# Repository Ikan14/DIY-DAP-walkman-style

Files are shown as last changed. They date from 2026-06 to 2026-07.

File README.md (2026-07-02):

# DIY-DAP-walkman-style
Hear your favourite music without any interruption by the palm of your hands,
with an old school vibes going on with DIY DAP Walkman style.

## Description 
  With ESP32 as the brain (Main processor) you could make a cheap DAP (Digital Audio Player) filled with your favouri♪te 
Music playlist, with ESP32 as the microcontroller, SD card module to filled with your Mp3 music files and some Audio jack 3.5 mm to hear it throught your earphone
with some niche button like the walkman has. And you could add display to make some UI ! >:D.

## Project Preview
Assembly 1 (4)
Assembly 1

## 3D model
Bwlow here is the full CAD assembly of the project, the .STEP files on the /CAD Files Folder
Assembly 1 (2)
Assembly 1 (4)

## Source Design
https://cad.onshape.com/documents/cdf923aa097df220a4b09fb1/w/958292e6abd58ac5f25ffee2/e/462f93d2c8d04da2a323aa71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

## Wiring Diagram
Shows how the ESP32 connect or wired with the DAC and other components


## Features :D
- Play Mp3 files by the SD card
- The button have contorol to Play/pause, Next, Previous
- 3.5 mm headphone or earphone outpur
- "Walkman Style" with 3D Printed case

## Component I use (almost everthing in module)
- ESP32-C3-DevKit module (mainboard)
- PCM5102 DAC Module with audiojack 3.5 mm
 (if the DAC module doesn't have any audio jack you need) audiojack 3.5 mm
- Micro SDcard Module
- OLED I2C 0.91'' inch
- MT608 Modul Step Up Boost DC to DC 2A USB Type-C
- TP4056 module TYPE-C
- 3.7 V 18650 li ion battery
- One battery holder
- 3 Push button

## BOM (Bill of Materials)
BOM Files on the /BOM (Bill Of Materials) folder ;)
Components List

| Name | Purpose | Qty | Total Cost (USD) | Source / Link | Distributor |
| :--- | :--- | :---: | :---: | :---: | :---: |
| **Tactile Switch** | As the control of the DAP | 3 | $0.17 | [Link](https://tk.tokopedia.com/ZSCdCuva5/) | Tokopedia |
| **One battery holder** | To hold the battery | 1 | $0.27 | [Link](https://tk.tokopedia.com/ZSCdCpkyx/) | Tokopedia |
| **3.7 V 18650 li-ion battery** | As the power supply | 1 | $0.49 | [Link](https://tk.tokopedia.com/ZSCdCrD4L/) | Tokopedia |
| **TP4056 module TYPE-C** | To charge up the battery | 1 | $0.34 | [Link](https://tk.tokopedia.com/ZSCdQsH1c/) | Tokopedia |
| **MT608 Modul Step Up Boost DC to DC 2A USB TYPE C** | For stepping up the current | 1 | $0.63 | [Link](https://tk.tokopedia.com/ZSCdQSWaG/) | Tokopedia |
| **OLED I2C 0.91'' inch Module** | As the screen | 1 | $1.76 | [Link](https://tk.tokopedia.com/ZSCdxTECL/) | Tokopedia |
| **Micro SD card module reader** | To store our music file | 1 | $0.56 | [Link](https://tk.tokopedia.com/ZSCdQ1gt9/) | Tokopedia |
| **PCM5102 DAC Module with audiojack 3.5 mm** | For changing Digital signal into Analog | 1 | $2.80 | [Link](https://tk.tokopedia.com/ZSCdxNCav/) | Tokopedia |
| **ESP32 C3 DevKit** | As the mainboard | 1 | $4.54 | [Link](https://tk.tokopedia.com/ZSCdxLQtW/) | Tokopedia |

---
*Note: Costs are estimation values in USD based on local distributor pricing.*

## Firmware
FIrmware is on the /Firmware folder and it is written using C++ in Arduino IDE framework

## Files Included
- CAD files (.STEP & source)
- Wiring Diagram
- BOM
- firmware

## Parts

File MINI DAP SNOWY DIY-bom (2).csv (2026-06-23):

Name | Purpose | Quantity | Total Cost (USD) | Link | Distributor
Tactile Switch | As the control of the DAP | 3 | 0.17 | https://tk.tokopedia.com/ZSCdCuva5/ | Tokopedia
One battery holder | To hold the battry | 1 | 0.27 | https://tk.tokopedia.com/ZSCdCpkyx/ | Tokopedia
3.7 V 18650 li ion battery | As the power supply | 1 | 0.49 | https://tk.tokopedia.com/ZSCdCrD4L/ | Tokopedia
TP4056 module TYPE-C | To charge up the battry | 1 | 0.34 | https://tk.tokopedia.com/ZSCdQsH1c/ | Tokopedia
MT608 Modul Step Up Boost DC to DC 2A USB TYPE C Type-C | For stepping Up the current | 1 | 0.63 | https://tk.tokopedia.com/ZSCdQSWaG/https://tk.tokopedia.com/ZSCdQSWaG/ | Tokopedia
OLED I2C 0.91'' inch Module | As the screen | 1 | 1.76 | https://tk.tokopedia.com/ZSCdxTECL/ | Tokopedia
Micro SDcard module reader | To store our music file | 1 | 0.56 | https://tk.tokopedia.com/ZSCdQ1gt9/ | Tokopedia
PCM5102 DAC Module with audiojack 3.5 mm | For changing Digital signal into Analog | 1 | 2.80 | https://tk.tokopedia.com/ZSCdxNCav/ | Tokopedia
ESP32 C3 DevKit | As the mainboard | 1 | 4.54 | https://tk.tokopedia.com/ZSCdxLQtW/ | Tokopedia

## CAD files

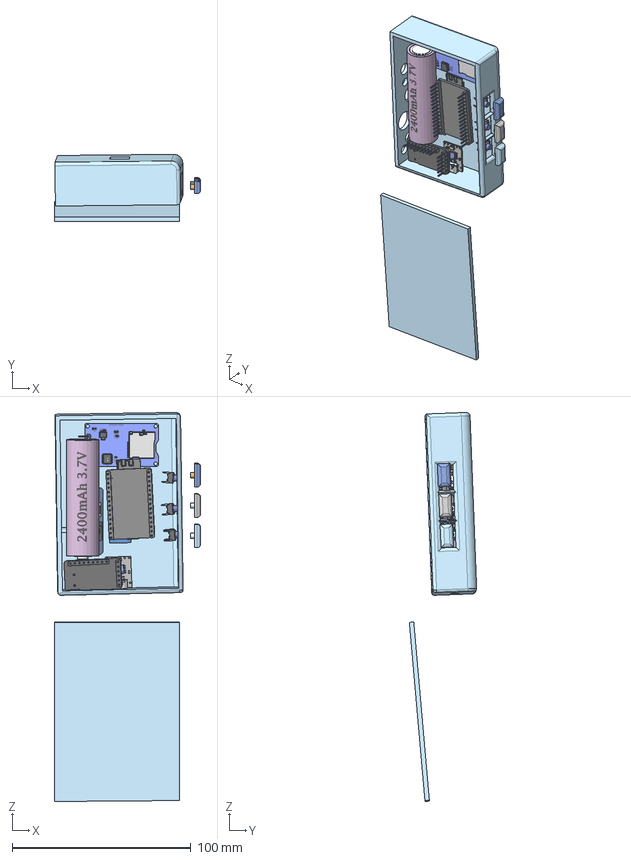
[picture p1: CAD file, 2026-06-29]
DAP_Walkman_v2_assembly.step
81.8 x 37.6 x 217.5 mm
TP4056 Mini x 29
Micro Momentary Tactile Tact Touch Push Button Switch, 6x6x6 mm v2 x 33
Surface 3
Valor predeterminado
2400mah li-ion cell v1 x 4
Surface 2
Surface 1
MT3608 v3 x 40
Pcb_e102
J2_PinHeader_1x09_P254mm_Vertical_94b9bb8abd76
J1_PinHeader_1x06_P254mm_Vertical_a7862d32d6b2
C13_C_0603_1608Metric_fe494fe29558 x 12
D1_LED_0603_1608Metric_b5c2f6ca02fa
R7_R_0603_1608Metric_fcd2d6c932f5 x 7
C2_C_0805_2012Metric_0ac201e7e1f9 x 2
U3_SOT_23_5_215b9efe0f9c x 2
U2_TSSOP_20_44x65mm_P065mm_d0068de2549f
J3_PJ-327A_7183a15533ae x 2
ESP32-C3-MINI-1_ESP32-C3-MINI-1 x 86
ESP32-C3-DEVKITM-1_ESP32-C3-DEVKITM-1 x 75
USB3080-30-00-A- x 12
CP2102N-A02-GQFN28_CP2102N-A02-GQFN28 x 31
1N5819HW-7-F_1N5819HW-7-F x 3
2SD0601A x 4
RESC-0603 x 39
Pin Header 4 x 1 TH 2.54mm Pitch x 8
OLED_0.91_128x32

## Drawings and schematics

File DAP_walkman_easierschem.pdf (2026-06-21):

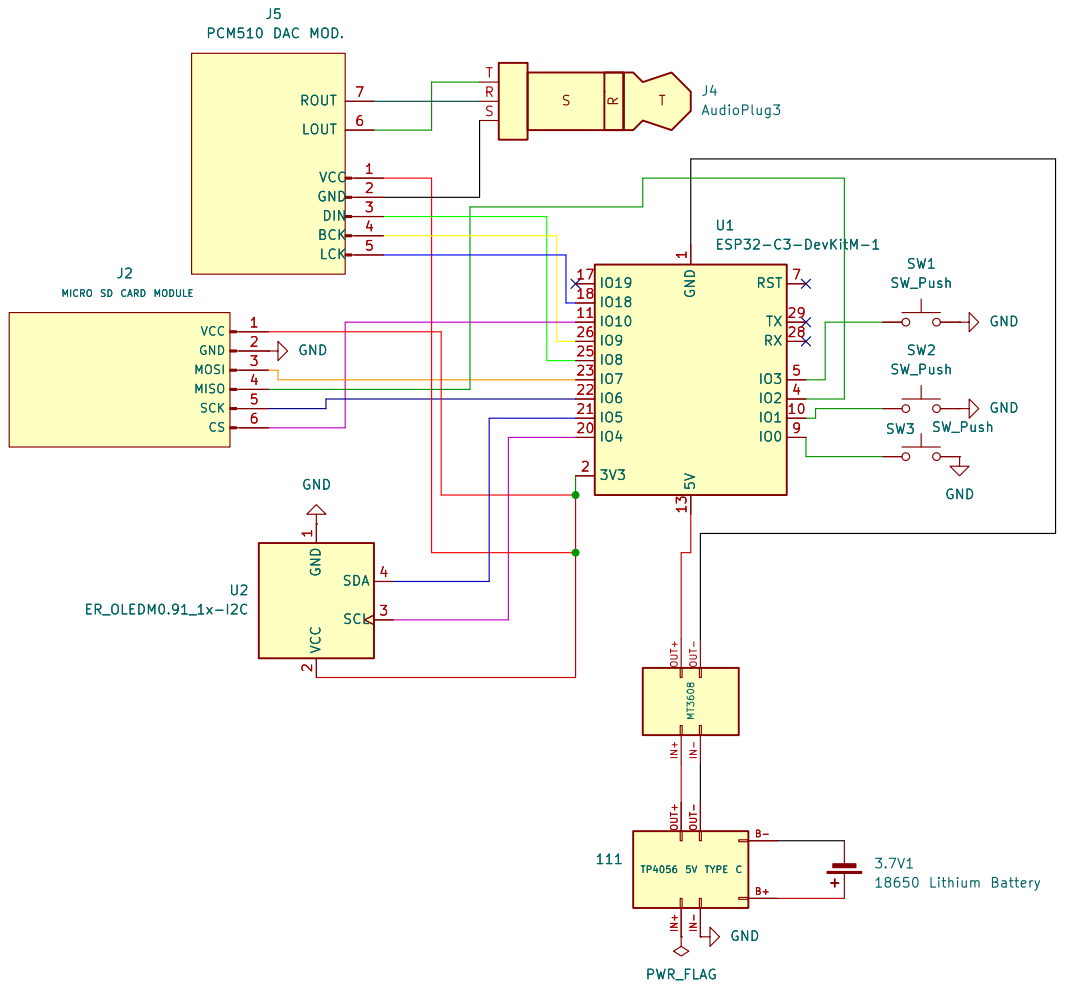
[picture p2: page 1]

Size: A4 | Rev:
KiCad E.D.A. 10.0.0 | Id: 1/1

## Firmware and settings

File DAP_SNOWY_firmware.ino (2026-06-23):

/*
 * MINI DAP SNOWY - Firmware v1.0
 * ESP32-C3 based Digital Audio Player
 * 
 * Pin Assignment:
 *   OLED  → SCL: IO4,  SDA: IO5
 *   SD    → MOSI: IO7, MISO: IO2, SCK: IO6, CS: IO10
 *   DAC   → DIN: IO8,  BCK: IO9,  LCK: IO18
 *   BTN   → SW1 (Play/Pause): IO3, SW2 (Next): IO1, SW3 (Prev): IO0
 * 
 * Libraries needed (install via Arduino Library Manager):
 *   - ESP8266Audio by Earle F. Philhower
 *   - U8g2 by oliver
 *   - SD (built-in ESP32)
 */

#include "Arduino.h"
#include "SD.h"
#include "SPI.h"
#include "Wire.h"
#include "U8g2lib.h"
#include "AudioFileSourceSD.h"
#include "AudioGeneratorMP3.h"
#include "AudioOutputI2S.h"

// ─── PIN DEFINITIONS ──────────────────────────────────────────
#define I2C_SCL     4
#define I2C_SDA     5

#define SD_MOSI     7
#define SD_MISO     2
#define SD_SCK      6
#define SD_CS       10

#define I2S_DIN     8
#define I2S_BCK     9
#define I2S_LCK     18

#define BTN_PLAY    3   // SW1 - Play / Pause
#define BTN_NEXT    1   // SW2 - Next track
#define BTN_PREV    0   // SW3 - Previous track

// ─── OBJECTS ──────────────────────────────────────────────────
U8G2_SSD1306_128X32_UNIVISION_F_HW_I2C oled(U8G2_R0, U8X8_PIN_NONE, I2C_SCL, I2C_SDA);

AudioGeneratorMP3 *mp3;
AudioFileSourceSD *file;
AudioOutputI2S    *out;

// ─── TRACK LIST ───────────────────────────────────────────────
#define MAX_TRACKS 50
char trackList[MAX_TRACKS][64];
int  trackCount   = 0;
int  currentTrack = 0;
bool isPlaying    = false;

// ─── BUTTON DEBOUNCE ──────────────────────────────────────────
unsigned long lastBtnPress[3] = {0, 0, 0};
#define DEBOUNCE_MS 200

// ─── HELPERS ──────────────────────────────────────────────────

// Scan SD root for .mp3 files
void scanTracks() {
  File root = SD.open("/");
  trackCount = 0;
  while (true) {
    File entry = root.openNextFile();
    if (!entry || trackCount >= MAX_TRACKS) break;
    String name = entry.name();
    if (!entry.isDirectory() && name.endsWith(".mp3")) {
      name = "/" + name;
      name.toCharArray(trackList[trackCount], 64);
      trackCount++;
    }
    entry.close();
  }
  root.close();
}

// Draw now-playing screen on OLED
void updateOLED() {
  oled.clearBuffer();
  oled.setFont(u8g2_font_6x10_tf);

  if (trackCount == 0) {
    oled.drawStr(0, 12, "No MP3 found!");
    oled.drawStr(0, 26, "Put files on SD");
  } else {
    // Track name (strip leading slash)
    String name = String(trackList[currentTrack]);
    if (name.startsWith("/")) name = name.substring(1);
    // Truncate if too long
    if (name.length() > 20) name = name.substring(0, 17) + "...";

    oled.drawStr(0, 10, isPlaying ? ">> NOW PLAYING" : "|| PAUSED");
    oled.drawStr(0, 22, name.c_str());

    // Track counter e.g. "2 / 5"
    String counter = String(currentTrack + 1) + " / " + String(trackCount);
    oled.drawStr(0, 32, counter.c_str());
  }
  oled.sendBuffer();
}

// Start playing currentTrack
void startTrack() {
  if (trackCount == 0) return;

  // Stop previous if running
  if (mp3 && mp3->isRunning()) {
    mp3->stop();
    delete mp3;
    delete file;
    mp3  = nullptr;
    file = nullptr;
  }

  file = new AudioFileSourceSD(trackList[currentTrack]);
  mp3  = new AudioGeneratorMP3();
  mp3->begin(file, out);
  isPlaying = true;
  updateOLED();
  Serial.printf("Playing: %s\n", trackList[currentTrack]);
}

void stopTrack() {
  if (mp3 && mp3->isRunning()) mp3->stop();
  isPlaying = false;
  updateOLED();
}

// ─── SETUP ────────────────────────────────────────────────────
void setup() {
  Serial.begin(115200);
  Serial.println("\n== MINI DAP SNOWY ==");

  // Buttons (INPUT_PULLUP → pressed = LOW)
  pinMode(BTN_PLAY, INPUT_PULLUP);
  pinMode(BTN_NEXT,  INPUT_PULLUP);
  pinMode(BTN_PREV,  INPUT_PULLUP);

  // OLED
  Wire.begin(I2C_SDA, I2C_SCL);
  oled.begin();
  oled.clearBuffer();
  oled.setFont(u8g2_font_6x10_tf);
  oled.drawStr(0, 16, "DAP SNOWY");
  oled.drawStr(0, 28, "Booting...");
  oled.sendBuffer();

  // SD Card
  SPI.begin(SD_SCK, SD_MISO, SD_MOSI, SD_CS);
  if (!SD.begin(SD_CS)) {
    Serial.println("SD Card FAILED!");
    oled.clearBuffer();
    oled.drawStr(0, 16, "SD Card Error!");
    oled.sendBuffer();
    while (true) delay(1000);
  }
  Serial.println("SD Card OK");

  // Scan tracks
  scanTracks();
  Serial.printf("Found %d tracks\n", trackCount);

  // I2S output → PCM5102
  out = new AudioOutputI2S();
  out->SetPinout(I2S_BCK, I2S_LCK, I2S_DIN);
  out->SetGain(0.8);  // 0.0 - 1.0 volume

  mp3  = nullptr;
  file = nullptr;

  updateOLED();

  // Auto-play first track
  if (trackCount > 0) startTrack();
}

// ─── LOOP ─────────────────────────────────────────────────────
void loop() {
  unsigned long now = millis();

  // ── Button: Play / Pause (SW1) ──
  if (digitalRead(BTN_PLAY) == LOW && now - lastBtnPress[0] > DEBOUNCE_MS) {
    lastBtnPress[0] = now;
    if (isPlaying) {
      stopTrack();
    } else {
      if (mp3 && !mp3->isRunning()) {
        mp3->begin(file, out);
        isPlaying = true;
        updateOLED();
      } else {
        startTrack();
      }
    }
  }

  // ── Button: Next (SW2) ──
  if (digitalRead(BTN_NEXT) == LOW && now - lastBtnPress[1] > DEBOUNCE_MS) {
    lastBtnPress[1] = now;
    currentTrack = (currentTrack + 1) % trackCount;
    startTrack();
  }

  // ── Button: Prev (SW3) ──
  if (digitalRead(BTN_PREV) == LOW && now - lastBtnPress[2] > DEBOUNCE_MS) {
    lastBtnPress[2] = now;
    currentTrack = (currentTrack - 1 + trackCount) % trackCount;
    startTrack();
  }

  // ── Feed audio decoder ──
  if (mp3 && mp3->isRunning()) {
    if (!mp3->loop()) {
      // Track finished → auto-next
      Serial.println("Track ended, playing next...");
      currentTrack = (currentTrack + 1) % trackCount;
      startTrack();
    }
  }
}

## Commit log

2026-04-07 Enhance README with project description and details
    Expanded project description to provide more details about the DIY DAP Walkman-style device, including its components and features.
2026-04-08 Create CAD Files
2026-04-08 Create Wiring Diagrams
2026-04-08 Create BOM (Bill Of Materials)
2026-04-08 BOM
    The BOM for MINI DAP
    [MINI DAP SNOWY DIY-bom (1).csv]
2026-06-21 WIring Diagram
2026-06-23 Update README
    Added detailed BOM entries with links and descriptions for components.
2026-06-23 Revise BOM format and fix battery descriptions
    Updated BOM section with a structured table format and corrected battery-related text.
2026-06-23 BOM (Bill of Material)
    [MINI DAP SNOWY DIY-bom (2).csv]
2026-06-29 Enhance README with project preview and wiring details
    Added project preview and 3D model sections with images. Updated wiring diagram description for clarity.
